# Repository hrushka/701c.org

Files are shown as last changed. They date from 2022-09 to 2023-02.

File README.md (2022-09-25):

# 👾 701c.org
This repo contains the open source assets for Project Butterfly - the [701c.org](https://701c.org) project.

## An enthusiasts guide to restoring and preserving an iconic portable.

I’ve made all the walkthroughs, guides, code, and assets I’ve created available free of charge. They are the results of countless hours of research, experimenting, and learning. I do all of this willingly at my own expense and because I have a passion for creating and preserving.



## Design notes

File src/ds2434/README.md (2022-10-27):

# 🦋 701c.org / Battery / DS2434 Clone  

Find the full rebuild and walkthrough at [https://701c.org/projects/battery](https://701c.org/projects/battery).

> **Note**: If you'd rather purchase a pre-built version of the board with the IC already programmed, you can do so from the [701c.org Shop](https://701c.org/shop).

#

## Background

The following is a clone of an obsolete 1-wire IC (Dallas DS2434) that any ThinkPad 701 battery needs in order to be recognized by the system and allowed to charge.

There is a lot of non-standard behavior that make this chip unique and why purchasing a DS2434 off eBay or Aliexpress won't get you very far.

It has been tested using an Arduino Uno developent board and can be compiled and run on an **ATtiny85** MCU. It uses the internal temperature sensing and recieves +3.3V power from the laptop so this is the only chip needed, making PCB design super straight forward.

This code requires a modified version of the awesome OneWireHub library by [Ingmar Inʒo Splitt (@orgua)](https://github.com/orgua) that you can find here: 

[https://github.com/hrushka/OneWireHub](https://github.com/hrushka/OneWireHub)

Special Thanks: 
-  Ingmar Inʒo Splitt (@orgua) for updates to the OneWireHub framework and initial code for the DS2434.
-  Karl Buchka for a lot of general knowledge and direction with MCUs and troubleshooting.

#

## Building the clone

1. Download [the code](https://github.com/hrushka/701c.org/tree/main/src/ds2434/ds2434.ino) and open it in the Arduino IDE.
   
2. Download the modified version of the [OneWireHub](https://github.com/hrushka/OneWireHub) as a Zip file.
   
3. In your Arduino IDE, go into *Sketch → Include Library →  Add .ZIP Library...* and select the downloaded zip file.
   
4. Open up your preferences and under "*Additional Boards Manager URLs*" add: https://raw.githubusercontent.com/damellis/attiny/ide-1.6.x-boards-manager/package_damellis_attiny_index.json

5. Close Preferences and under the *Tools* menu select the following:
   1. **Board**: ATtiny 25/45/85
   2. **Processor**: ATtiny85
   3. **Clock**: Internal 16mhz
   4. **Port**: [*your programmer*]

6. In order to configure the ATtiny and set the clock to 16mhz, select "*Burn bootloader*".

7. Once this is complete, you should be able to upload the code directly to the ATtiny without any additional setup.

> **Note**: The ATtiny version of the code measures the temperature by checking the voltage resistance and uses a baseline. Depending on your chip/package selection you may want to calibrate the values in the **chipTemp()** function. Instructions on how to do this can be found here: http://www.atmel.com/Images/doc8108.pdf

#

## The PCB

If you'd like to print your own PCB, you can [download the latest Gerber files here](https://github.com/hrushka/701c.org/tree/main/assets/battery/gerber). There is also a version that will work with the original DS2434 IC in case you happen to have one you've pulled form an original battery.

The PCB has been tested with the following surface mount packages:
- [ATTINY85-20SF](https://www.findchips.com/search/ATTINY85-20SF)
- [ATTINY85-20SFR](https://www.findchips.com/search/ATTINY85-20SFR)

#

## Things to know...

1. Any new battery/cells need to be calibrated. Before the ThinkPad will show an accurate charge level or function properly, it will need to go through a full charge/discharge cycle. Charge the battery fully until the green light turns off on its own, then unplug and let the battery fully discharge. Repeat the charge cycle and you should be good to go. You can press **FN+F2** at any time to see the current charge and estimated time left.

2. The battery has been tested with **Ni-Cad** and **Ni-MH** type batteries. I do not know how the chip or laptop will behave if you use another chemistry like **Lithium-ion**. All of the reference chips I used were pulled from original **Ni-Cad** batteries.

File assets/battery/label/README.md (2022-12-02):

# 👾 701c.org / Battery / Label  

Find the full rebuild and walkthrough at [https://701c.org/projects/battery](https://701c.org/projects/battery).

> You're free to print this yourself, or you can purchase a PVC label printed on metallic paper (just like the original) at the [701c.org Shop](https://701c.org/shop).

The label is designed to be an exact match for the original battery and also fits the 3D printed case.

There are two versions with updated battery chemistries:

1. Ni-MH for Nickel Metal Hydryde
2. Li-Po for Lithium Polymer

> The 701c logo is pink in color to denote an area where the metallic silver should show through.

| Property | Value |
| --- | --- |
| Material | BOPP |
| Back | Metallic Silver Silver |
| Height | 34.5 mm |
| Width | 198 mm |
| Corner Radius * | 1.5 mm |
| Gray Color | [Pantone 2330 C](https://www.pantone.com/connect/2330-C) |
| Yellow Color | [Pantone 114 C](https://www.pantone.com/connect/114-C) |

\* The top left corner has a custom notch cut out

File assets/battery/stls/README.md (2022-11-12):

# 👾 701c.org / Battery / PCB  

Find the full rebuild and walkthrough at [https://701c.org/projects/battery](https://701c.org/projects/battery).

The files are broken up into 3 pieces for ease of printing. Find all the print settings at the link above.

## Example Printer Settings (FDM)

| Property | Value |
| --- | --- |
| Printer | Creality Ender 3 |
| Filament | Fulament Matte PLA |
| Build Plate | Fulament Fula-Flex 2.0 |
| Bed Temperature | 59° |
| Print Temperature | 215° |
| Nozzle | 0.4 mm |
| Layer Height | 0.12 mm |
| Supports | All |
| Overhang | 20% |

## Example Printer Settings (SLA)

| Property | Value |
| --- | --- |
| Printer | Elegoo Saturn 2 8k |
| Resin | Anycubic Eco UV Resin (Black) |
| Model Angle | 60.3° |
| Layer Height | 25µm |
| Exposure Time | 3.5s |
| Bottom Exposure Time | 35s |
| Supports | Medium - Platform Only |

> **Note on materials**: The models are thin and long which are prone to warping under heat. If you are planning on having these printed profesionally, make sure to use a material that has a high heat tollerance, especially if being shipped from over seas.
>

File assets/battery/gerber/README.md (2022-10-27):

# 👾 701c.org / Battery / PCB  

Find the full rebuild and walkthrough at [https://701c.org/projects/battery](https://701c.org/projects/battery).

Use the gerber files to print your own PCBs at vencors like [PCBWay](https://pcbway.com) or [JLPCB](https://jlpcb.com).

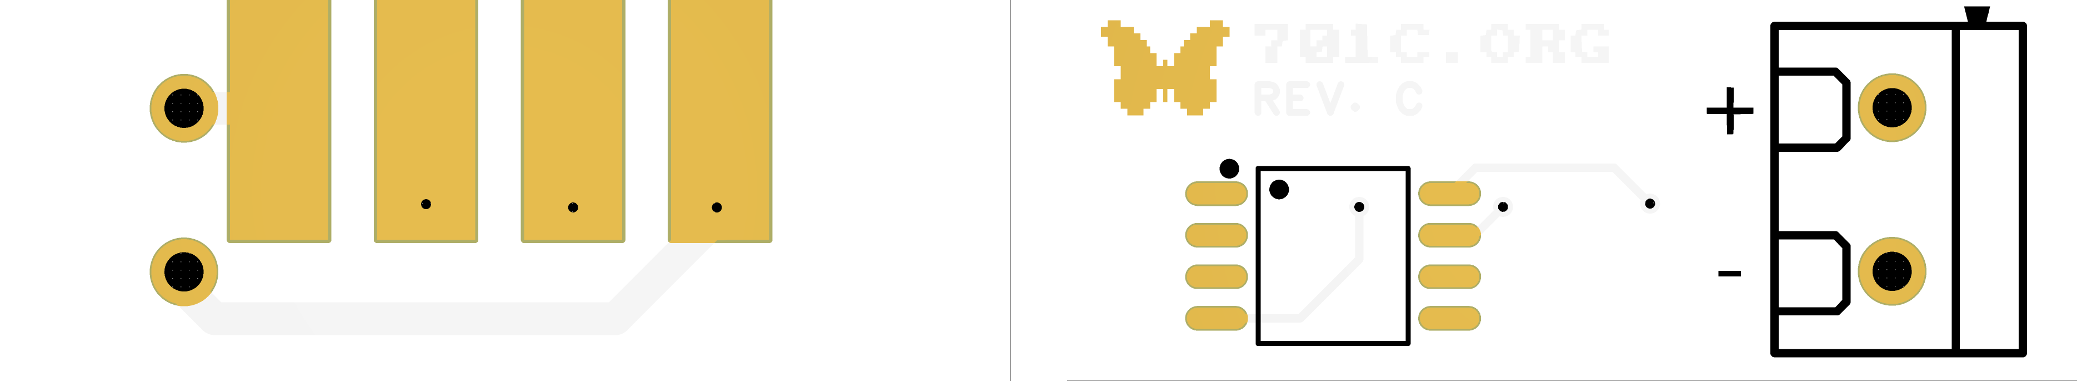
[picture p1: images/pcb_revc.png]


> If you would prefer to purchase a single board rather than printing them yourself, you can do so at the [701C.org Shop](https://701c.org/shop).

## Example Printer Settings

| Property | Value |
| --- | --- |
| Layers | 2 |
| Width | 31 mm |
| Height | 11.6 mm |
| Thickness | 1 mm |
| Finish | ENIG (Immersion gold) |

## Required Components

| Component | Part # |
| --- | --- |
| Terminals | KF301-2P 5.08mm |
| MCU | [ATTINY85-20SF](https://www.findchips.com/search/ATTINY85-20SF) or [ATTINY85-20SFR](https://www.findchips.com/search/ATTINY85-20SFR) |

The code for the MCU can be found [here](https://github.com/hrushka/701c.org/tree/main/src/ds2434).

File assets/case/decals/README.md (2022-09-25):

# 👾 701c.org / Case / Decals  

Find application instructions and a full walkthrough at [https://www.701c.org/projects/painting-decals](https://www.701c.org/projects/painting-decals).

> Dry transfers can be expensive to print. If you'd like to purchase a single set already printed, you can do so from the [701C.org Shop](https://701c.org/shop).

The decals are acurately sized down to the fraction of a milimeter. The page is intended to be printed fully scaled to an 8.5 x 11 sheet. You will see reference measurements on the sheet to make sure you've printed the correct size.

I've tried multiple ways of adhering decals to the case. By far the best quality has been by using profesionally printed dry transfers.

Use the guide linked above for application instructions.

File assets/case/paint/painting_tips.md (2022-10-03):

# 👾 701c.org / Case / Paint  

Find application instructions and a full walkthrough at [https://www.701c.org/projects/painting-decals](https://www.701c.org/projects/painting-decals).

##  Painting Tips

Getting a great paint job with a can of spraypaint using cardboard in your back yard is absolutely possible. There are - however - a lot of ways you could have issues. Many of these things are minimized or eliminated by using professional paint rooms and equipment, but it doesn't mean you can acheive similar results if you know the pitfalls and how to avoid them.

Below is a list of common issues that can come up and some of the possible reasons/solutions.

| Issue | Possible Cause | Solution |
| --- | --- | --- |
| Rough / Grainy Finish | | |
|

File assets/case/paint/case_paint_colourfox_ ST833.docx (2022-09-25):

Serie : SPECIAL FINISHING

SOFT TOUCH ANTI SCRATCH

Référence : ST833

Version: 17/05/2020

TECHNICAL DATA FILE

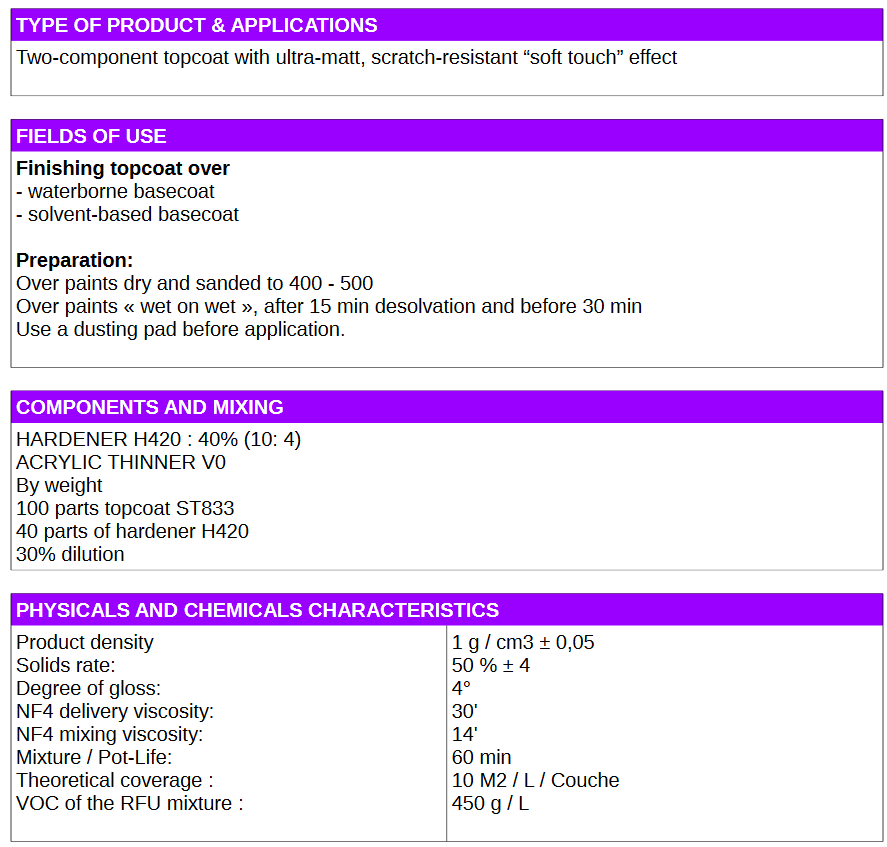
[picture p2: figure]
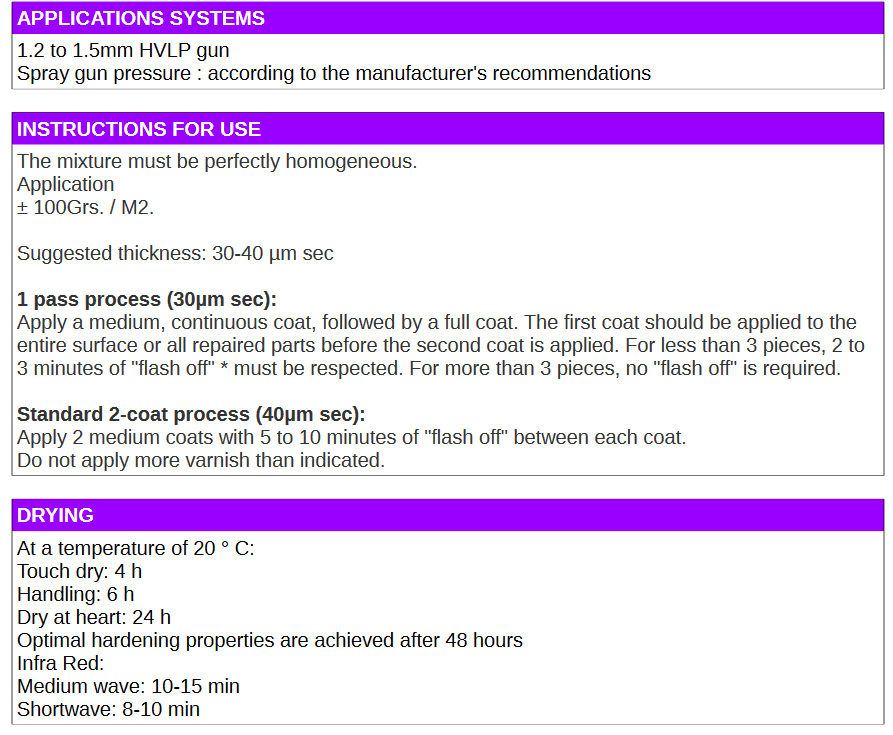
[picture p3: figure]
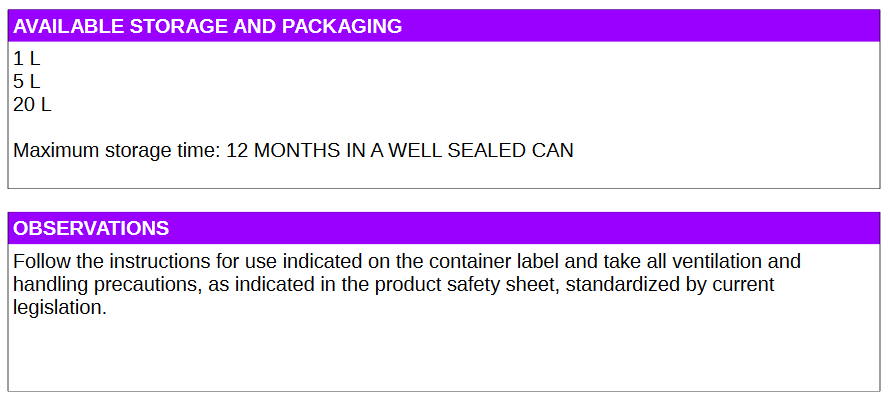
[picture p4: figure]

COLOURFOX PAINTS BARCELONA – SPAIN TEL.- (+34) 93 117 17 87 – MOV.- (+34) 675 90 71 98 EMAIL: info@colourfox.com www.colourfox.com – www.garygandara.com

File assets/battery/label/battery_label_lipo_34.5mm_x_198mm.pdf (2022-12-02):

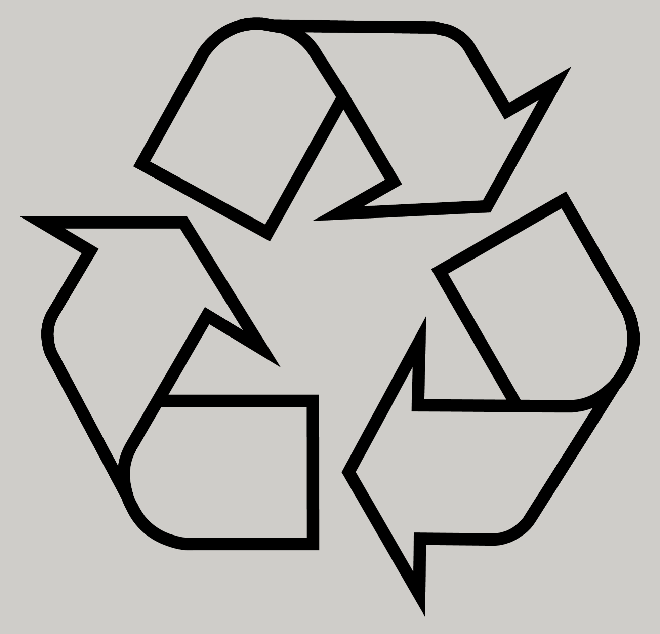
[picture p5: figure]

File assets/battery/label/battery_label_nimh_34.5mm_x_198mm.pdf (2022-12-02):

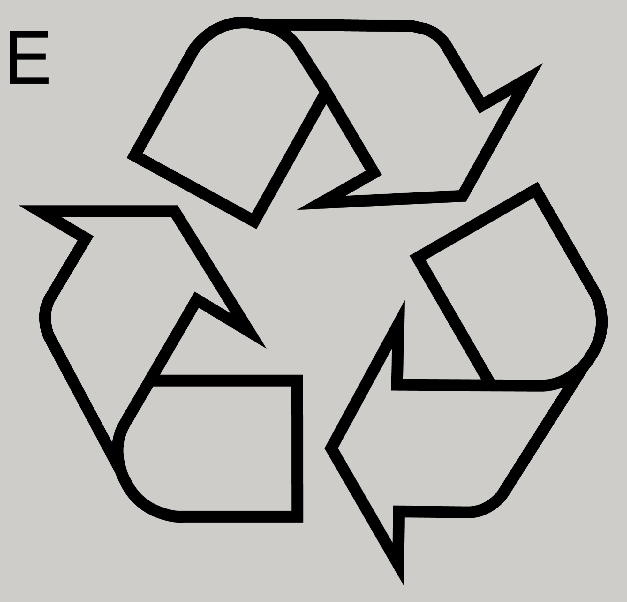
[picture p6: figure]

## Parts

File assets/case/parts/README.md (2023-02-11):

# 🦋 701c.org / Case / Parts

Find more details on reproduction parts at [https://701c.org/projects/parts](https://701c.org/projects/parts).

> **Note**: From time to time there may be limited quantities of these parts available in the [701c.org Shop](https://701c.org/shop).

#

## Background

Clips, slides, port covers, and battery doors; these things can get easily damaged when the plastic begins to deteriorate or go missing entirely if they’re not fully attached. Here is a list of high-quality models I’ve made to replace the common components on the 701C body. 

As many of these parts are very detailed, I’ve included the settings I use below for high-resolution 3D SLA printers along with suggested resins.

#

## PCMCIA Cover with Popout

Download the STLs:
   * For the main cover [here](https://github.com/hrushka/701c.org/blob/main/assets/case/parts/ibm_tp701_pcmciacover_main.stl).
   * For the popout [here](https://github.com/hrushka/701c.org/blob/main/assets/case/parts/ibm_tp701_pcmciacover_center.stl).

### Example Printer Settings (SLA)

| Property | Value |
| --- | --- |
| Printer | Elegoo Saturn 2 8k |
| Resin MIX | 60% ABS-Like / 40% F69 (Flexible) |
| Print Angle | 48.743° |
| Supports | Light |
| Layer Height | 25µm |
| Exposure Time | 5s |
| Bottom Exposure Time | 50s |
| Ambient Temperature | 31°C |

I've modified the parts and now recommend printing both at the angle above or - more importantly - using the [angle calculator](https://www.rc87.blog/angle-calculator/) to find the appropriate angle for your printer and layer height.

**See the note below about calculating the correct angle for your print.**

#

## RAM Door Cover & Sleep Battery Cover

Download the Ram Door Cover STL [here](https://github.com/hrushka/701c.org/blob/main/assets/case/parts/ibm_tp701_ramcover.stl).

Download the Sleep Battery Cover STL [here](https://github.com/hrushka/701c.org/blob/main/assets/case/parts/ibm_tp701_sleepcover.stl).

### Example Printer Settings (SLA)

| Property | Value |
| --- | --- |
| Printer | Elegoo Saturn 2 8k |
| Resin MIX | 60% ABS-Like / 40% F69 (Flexible) |
| Print Angle | 48.743° |
| Supports | Light |
| Layer Height | 25µm |
| Exposure Time | 5s |
| Bottom Exposure Time | 50s |
| Ambient Temperature | 31°C |

I've modified the parts and now recommend printing both at the angle above or - more importantly - using the [angle calculator](https://www.rc87.blog/angle-calculator/) to find the appropriate angle for your printer and layer height.

#

## Floppy Disk (FDD) Port Cover

Download the STL [here](https://github.com/hrushka/701c.org/blob/main/assets/case/parts/ibm_tp701_portcover.stl).

### Example Printer Settings (SLA)

| Property | Value |
| --- | --- |
| Printer | Elegoo Saturn 2 8k |
| Resin MIX | **100% F69 (Flexible)** |
| Print Angle | Face down on build plate |
| Print Supports | 2 small light supports for the "clip" overhang MAY be needed |
| Layer Height | **50µm** |
| Exposure Time | **7.6s** |
| Bottom Exposure Time | 50s |
| Ambient Temperature | 31°C |

You may get a clean print without supports, but I add two custom light supports to the overhang of the clip and then trim them after washing and before curing.

#

## Things to know...

1. Make sure your resin is mixed well and allow the resin to pre-heat in the enclosure or the tank for 30 minutes before printing. I have found that when using flexible resins like F69, temperature is incredibly important to prevent the resin from becoming too viscous.
   
2. If your printer is different or you print at a different layer height you must **recalculate the angle of the print**. I suggest using an angle calculator like the one provided by [RC87](https://www.rc87.blog/angle-calculator/).

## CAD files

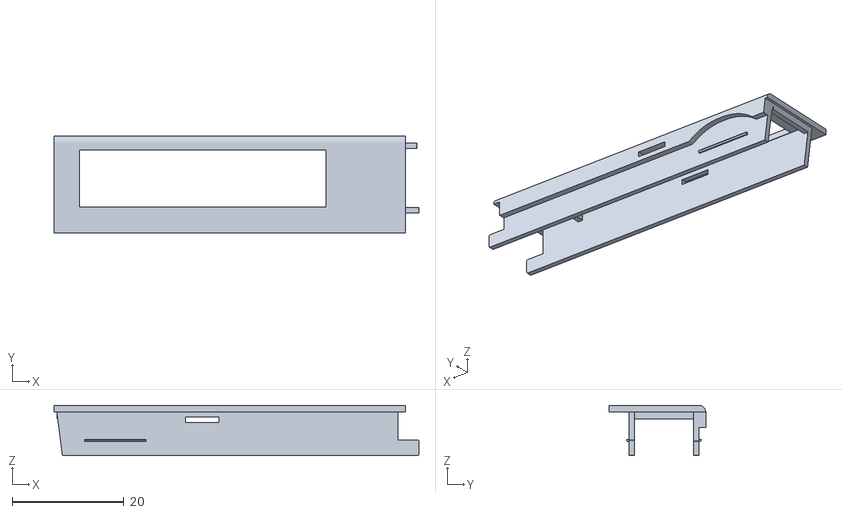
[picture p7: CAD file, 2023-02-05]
assets/case/parts/ibm_tp701_pcmciacover_main.stl
65.4 x 17.3 x 9.00

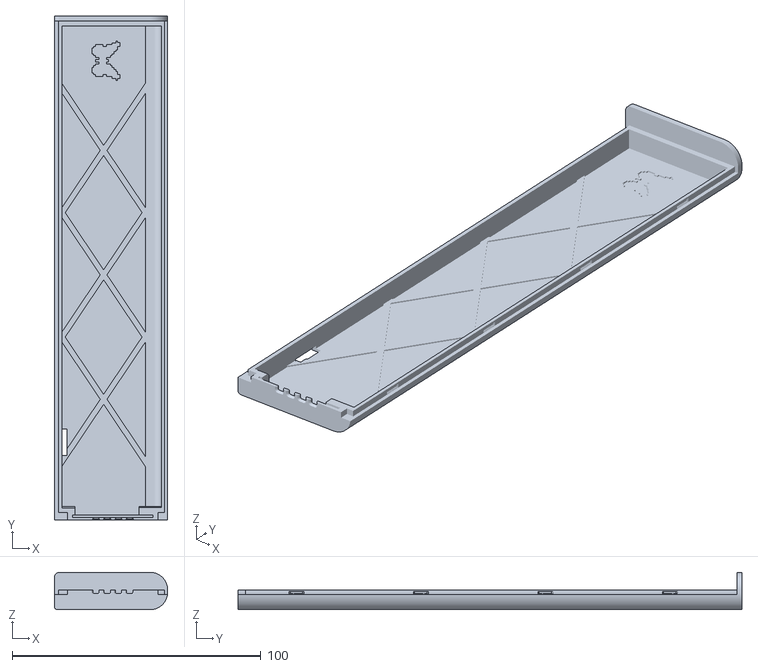
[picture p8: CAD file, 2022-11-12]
assets/battery/stls/battery_case_stls_latest/ibm_tp701_batt_v3_bottom.stl
45.5 x 202.5 x 15.0

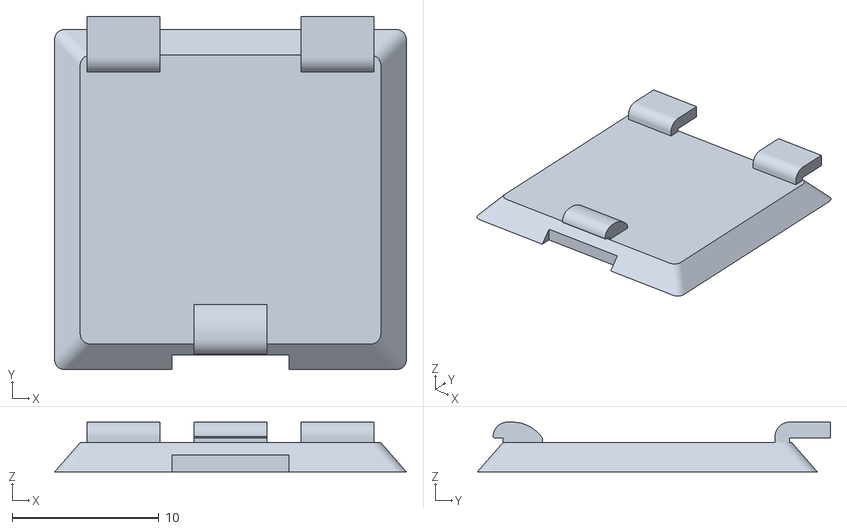
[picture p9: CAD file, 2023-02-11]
assets/case/parts/ibm_tp701_sleepcover.stl
24.0 x 24.1 x 3.40

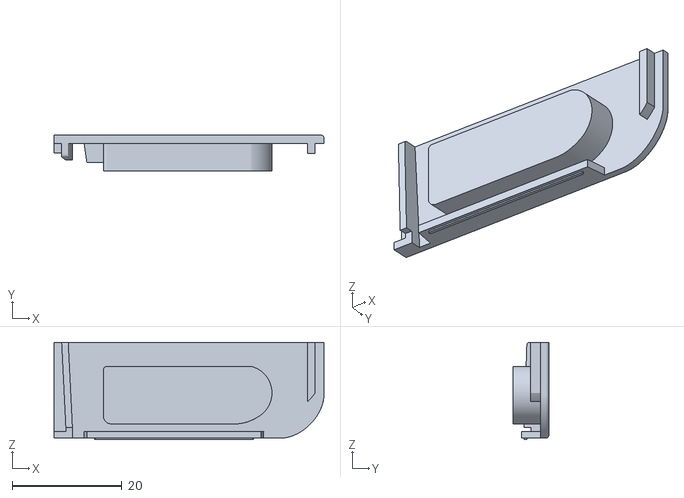
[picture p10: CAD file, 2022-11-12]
assets/battery/stls/battery_case_stls_latest/ibm_tp701_batt_v3_front.stl
49.3 x 6.50 x 17.8

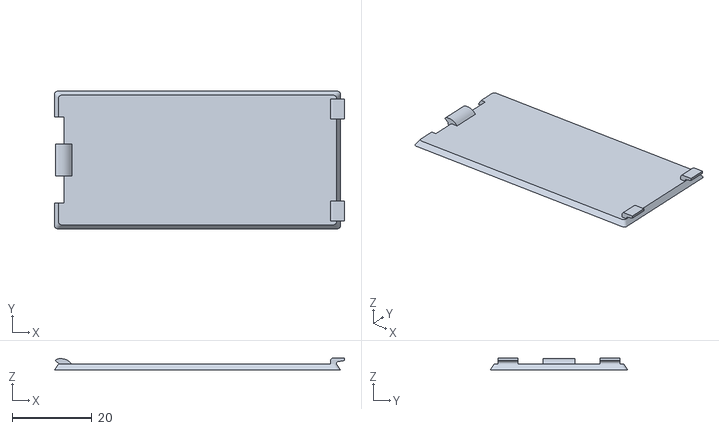
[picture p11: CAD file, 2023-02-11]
assets/case/parts/ibm_tp701_ramcover.stl
72.6 x 34.5 x 3.05

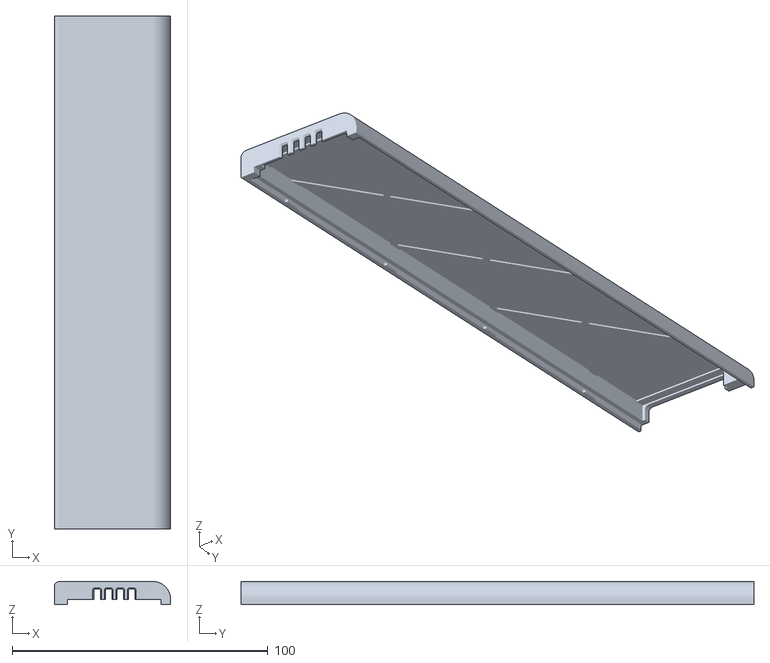
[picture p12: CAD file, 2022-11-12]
assets/battery/stls/battery_case_stls_latest/ibm_tp701_batt_v3_top.stl
45.4 x 200.5 x 9.00

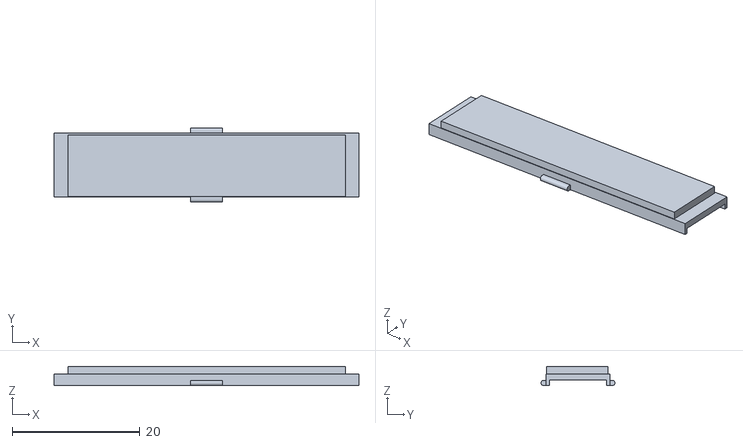
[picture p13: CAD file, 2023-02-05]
assets/case/parts/ibm_tp701_pcmciacover_center.stl
47.8 x 11.6 x 3.00

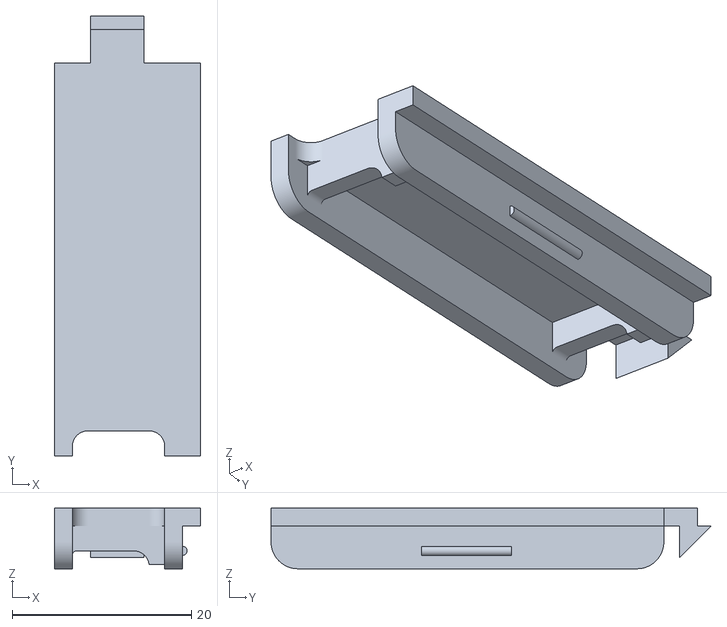
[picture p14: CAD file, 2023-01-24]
assets/case/parts/ibm_tp701_portcover.stl
16.3 x 49.0 x 6.75

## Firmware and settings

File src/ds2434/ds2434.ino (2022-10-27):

/*
*   This code emulates a DS2434 with Battery Management, Temperature & EEPROM
*   It was designed specifically for use with an IBM ThinkPad 701c Battery (or rebuild)
*
*   Tested with
*    - 1995 IBM ThinkPad 701CS as Master, Arduino Uno and attiny85@16MHz as Slave
*
*   Author: hrushka (701c.org)
*   Required: https://github.com/hrushka/OneWireHub - a modified version of the original
*   
*   Special Thanks: 
*    -  Ingmar Inʒo Splitt (@orgua) for updates to the OneWireHub framework
*       and initial code for the DS2434.
*    -  Karl Buchka for a lot of general knowledge and direction with MCUs 
        and troubleshooting 
*/

#include "OneWireHub.h" // https://github.com/hrushka/OneWireHub
#include "DS2434.h"

#if defined(ARDUINO_AVR_UNO)
constexpr uint8_t pin_onewire   { 7 }; // for Arduino Uno
#else
constexpr uint8_t pin_onewire   { 2 }; // for attiny
#endif

constexpr uint8_t tempCheckInterval = 5000;
unsigned long     lastTempCheck     = 0; 
unsigned long     time_now          = 0;
uint8_t           lastTemp          = 20;

auto hub = OneWireHub(pin_onewire);
auto ds2434 = DS2434(0x00, 0x00, 0x00, 0x00, 0x00, 0x00, 0x00); // Serial & family not used for DS2434

/*
 * We need to initialize the memory for the read of the chip and
 * set up for internal temp sensing.
 */
void setup()
{
    // Setup OneWire
    hub.attach(ds2434);

    // Check to see if we should restore memory from EEPROM.
    if(!ds2434.checkRestoreMemory()){

        // No memory was found in the EEPROM, load defaults
        constexpr uint8_t mem1[24] = {0x14, 0x10, 0x90, 0xd0, 0x03, 0x32, 0x4b, 0x3c,
                                  0xff, 0x04, 0x64, 0x04, 0x9e, 0x9a, 0x3a, 0xf0,
                                  0x00, 0x00, 0x04, 0xee, 0x63, 0xB8, 0x3E, 0x63 };
        ds2434.writeMemory(reinterpret_cast<const uint8_t *>(mem1),sizeof(mem1),0x00);

        constexpr  uint8_t mem2[8] = {0x33, 0x2e, 0x33, 0x2e, 0x9e, 0x10, 0x3f, 0x50 };
        ds2434.writeMemory(reinterpret_cast<const uint8_t *>(mem2),sizeof(mem2),0x20);

        ds2434.setID(0xCABDu);
        ds2434.setBatteryCounter(0x0101u);

        // Tell the system to save the defaults to EEPROM
        ds2434.persistAllMemory();
    }

    ds2434.unlockNV1();

    // Setup the Analog to Digital Converter for internal temp sensing
    ADCSRA &= ~(_BV(ADATE) |_BV(ADIE)); // Clear auto trigger and interrupt enable
    ADCSRA |= _BV(ADEN);                // Enable AD and start conversion
    ADMUX = 0xF | _BV( REFS1 );         // ADC4 (Temp Sensor) and Ref voltage = 1.1V;
    delay(100);                         // Settling time min 1 ms, take 100 ms
    getADC();
}

void loop()
{
    // following function must be called periodically
    hub.poll();

    if (ds2434.getTemperatureRequest()){

      time_now = millis();

      /*
       * Only check for a new temperature every so often to mimize blocking.
       * All other times, report back the last temp recorded.
       */
      if(time_now >= (lastTempCheck + tempCheckInterval)){
          uint8_t temp = getInternalTemp();
          ds2434.setTemperature(temp);
          lastTempCheck = time_now;
          lastTemp = temp;
      } else {
          ds2434.setTemperature(lastTemp);
      }
    }


    hub.poll();

    // Check to see if we need to persist the memory
    ds2434.checkPersistMemory(hub);
}

/* 
 * getInternalTemp() Uses the internal temperature sensor of the attiny85
 * Tested with ~3.3V VCC on the ThinkPad 701C laptop
 * Adapted from: https://21stdigitalhome.blogspot.com/2014/10/trinket-attiny85-internal-temperature.html
*/
int8_t getInternalTemp(){

  // Arduino doesn't have the same ability. Return back a static temp.
  #if defined(ARDUINO_AVR_UNO)
  return 20;
  #else

  int i;
  int t_celsius; 
  uint8_t vccIndex;
  float rawTemp, rawVcc;
  
  // Measure temperature
  ADCSRA |= _BV(ADEN);           // Enable AD and start conversion
  ADMUX = 0xF | _BV( REFS1 );    // ADC4 (Temp Sensor) and Ref voltage = 1.1V;
  
  // Pause for settling time, but keep polling to pick up reset/presence polls
  delayWhilePolling(100);

  rawTemp = (float)getADC();     // use next sample as initial average
  for (int i=2; i<2000; i++) {   // calculate running average for 2000 measurements
    rawTemp += ((float)getADC() - rawTemp) / float(i); 
  }  
  ADCSRA &= ~(_BV(ADEN));        // disable ADC  

  // Measure chip voltage (Vcc)
  ADCSRA |= _BV(ADEN);           // Enable ADC
  ADMUX  = 0x0c | _BV(REFS2);    // Use Vcc as voltage reference,
                                 //    bandgap reference as ADC input

  // Pause for settling time, but keep polling to pick up reset/presence polls
  delayWhilePolling(100);
                                
  rawVcc = (float)getADC();      // use next sample as initial average
  for (int i=2; i<2000; i++) {   // calculate running average for 2000 measurements
    rawVcc += ((float)getADC() - rawVcc) / float(i);
  }
  ADCSRA &= ~(_BV(ADEN));        // disable ADC
  
  rawVcc = 1024 * 1.1f / rawVcc;
  //index 0..13 for vcc 1.7 ... 3.0
  vccIndex = min(max(17,(uint8_t)(rawVcc * 10)),30) - 17;   

  /*
   * Temperature compensation using the chip voltage 
   * The 701c measures 3.22 V going to the DS2434 
   */
  t_celsius = (int)(chipTemp(rawTemp) + (float)vccIndex / 13); 

  return t_celsius;
  #endif
}

/*
 * Delay the current procedure while still polling so that no requests/resets/presence 
 * are dropped in the process.
 */
 void delayWhilePolling(uint8_t delay){
    time_now = millis(); // deliberate reuse of the global variable
    while(millis() < time_now + delay){
      hub.poll();
    }
 }

/* 
 * Calibration of the temperature sensor has to be changed for your own ATtiny85
 * per tech note: http://www.atmel.com/Images/doc8108.pdf
*/
float chipTemp(float raw) {
  const float chipTempOffset = 282.9;           // Your value here, it may vary 
  const float chipTempCoeff  = 1.075;           // Your value here, it may vary
  return((raw - chipTempOffset) / chipTempCoeff);
}

/*
 * Common code for both sources of an ADC conversion
 */
int getADC() {
  ADCSRA  |=_BV(ADSC);            // Start conversion
  while((ADCSRA & _BV(ADSC)));    // Wait until conversion is finished
  return ADC;
}

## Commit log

2022-09-30 Updated colors on battery label.
2022-10-22 Fixed pin mixup in definition.
    [ds2434.ino]
2022-10-27 Fixed pin assignment
2022-10-27 Updates to the PCB
2022-10-27 Readme updates - boards now available.
2022-11-12 New re-enforced case STLs
    [ibm_tp701_batt_v3_bottom.stl, ibm_tp701_batt_v3_front.stl, ibm_tp701_batt_v3_top.stl]
2022-12-02 Added two battery chemistries.
2023-01-24 Added new case STLs
    [ibm_tp701_pcmciacover_center.stl, ibm_tp701_pcmciacover_main.stl, ibm_tp701_portcover.stl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]
2023-02-05 Updates to PCMCIA cover.
    [ibm_tp701_pcmciacover_center.stl, ibm_tp701_pcmciacover_main.stl]
2023-02-11 Added Sleep Battery cover
    [ibm_tp701_ramcover.stl, ibm_tp701_sleepcover.stl]
